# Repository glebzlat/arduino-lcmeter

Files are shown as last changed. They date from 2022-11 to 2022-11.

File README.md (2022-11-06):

## Arduino LC-meter

Простой измеритель емкости/индуктивности на Arduinо. Диапазон измерений: от ~90 пФ/мкГн до ~6 мкФ/Гн.

### Функционал

Кнопка J2 Calibration служит для программной коррекции нуля, что компенсирует начальное смещение нуля ОУ, а также емкость и индуктивность клемм и переключателя SW1. Нужный диапазон выбирается автоматически, причем после включения питания измерение начинается с 9 диапазона.

В процессе переключения диапазонов частота возбуждающего напряжения и результат преобразования АЦП отображаются в нижней строке индикатора. Это справочная информация, которая может помочь оценить корректность измерения параметров. Через несколько секунд после стабилизации показаний эта строка индикатора очищается, чтобы не отвлекать внимание пользователя.

Результат измерения отображается в верхней строке. Измеренное значение напряжения с выхода ОУ интерпретируется как емкость или индуктивность в зависимости от положения переключателя J3 MODE.

### Настройка

Прибор имеет два подстроечных резистора, предназначенных для настройки правильности показаний значения емкости и индуктивности. Их надо настроить после сборки и в дальнейшем трогать их не нужно. Для этой процедуры требуется парочка конденсаторов и индуктивностей с точностью хотя бы 5%.

### Как это работает

Принцип измерения заключается в подаче меандра на измеряемый конденсатор или индуктивность и преобразовании тока разряда конденсатора (или тока индуктивности) в напряжение, которое сглаживается и подается на АЦП Arduino. При измерении емкости конденсатор во время положительного полупериода заряжается через резистор R6 и диод D5, во время отрицательного разряжается через резистор R6 и диод D1, и его разрядный ток поступает на вход 2 U1. При измерении индуктивности во время положительного полупериода ток в катушке нарастает до значения, определяемого номиналом резистора R7, а во время отрицательной - ток, создаваемый ЭДС самоиндукции через D2 и R2, RV2 также поступает на вход U1. Ток разряда конденсатора (а, значит, и напряжение на выходе измерителя) прямо пропорционален его емкости, если конденсатор успевает полностью зарядиться за положительный полупериод и полностью разрядиться за отрицательный. Также и ток самоиндукции катушки прямо пропорционален ее индуктивности, если ток в ней успевает нарастать до максимального значения и спадать до нуля.

Для этого частота автоматически изменяется от 1 мегагерца до 15 герц в зависимости от значения напряжения на выходе измерителя. Прибор имеет 9 диапазонов измерения, и на каждом последующем диапазоне частота снижается, а предел измерения увеличивается в 4 раза. На первом диапазоне частота равна 1 МГц, и максимальное измеряемое значение ~90 пФ/мкГн.

| Диапазон | Частота (МГц) | Макс. емкость (Ф) | Макс. индуктивность (Гн) |
|---|---|---|---|
| 1 | 1.000.000 | 8,92e-11 | 8,92e-5 |
| 2 | 250.000 | 3,56e-10 | 3,56e-4 |
| 3 | 62.500 | 1,42e-9 | 1,42e-3 |
| 4 | 15.625 | 5,70e-9 | 5,70e-3 |
| 5 | 3.906 | 2,28e-8 | 2,28e-2 |
| 6 | 976 | 9,13e-8 | 9,13e-2 |
| 7 | 244 | 3,65e-7 | 3,65e-1 |
| 8 | 61 | 1,46e-6 | 1,46 |
| 9 | 15 | 5,84e-6 | 5,84 |

### Источники

https://ra4nal.ontvtime.ru/lc_arduino.shtml

Журнал Радио №3 1982

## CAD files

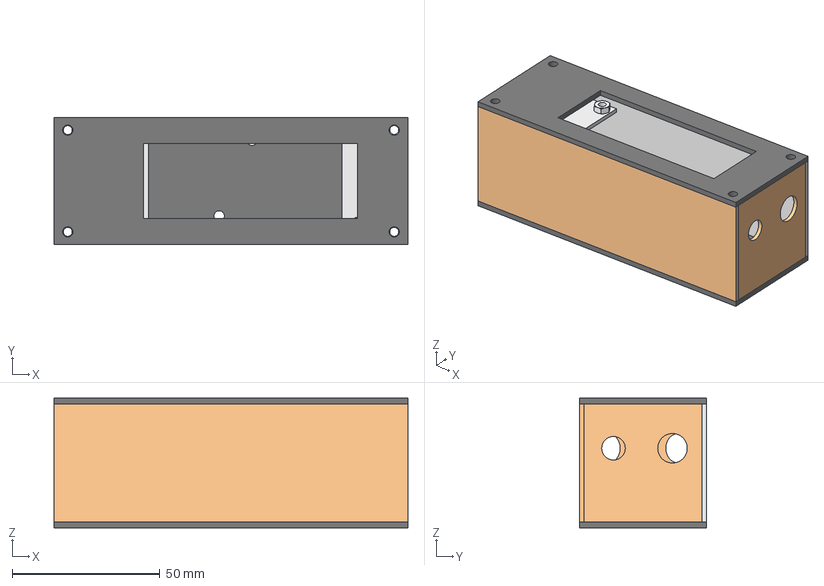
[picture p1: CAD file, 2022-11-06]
lc_meter_frame.FCStd
120.0 x 43.0 x 44.0 mm
Screw M3 001
Screw M3 001 (Mirror #2)
Screw M3 001 (Mirror #3)
Screw M3 001 (Mirror #1)
Screw M3 001 (Mirror #5)
Screw M3 001 (Mirror #6)
Screw M3 001 (Mirror #7)
Screw M3 001 (Mirror #4)
Screw M3 002
Screw M3 003
Screw M3 004
Screw M3 005
Side Panel 2
Side Panel 4
Side Panel 3
Side Panel 1
Bottom Panel
Top Panel

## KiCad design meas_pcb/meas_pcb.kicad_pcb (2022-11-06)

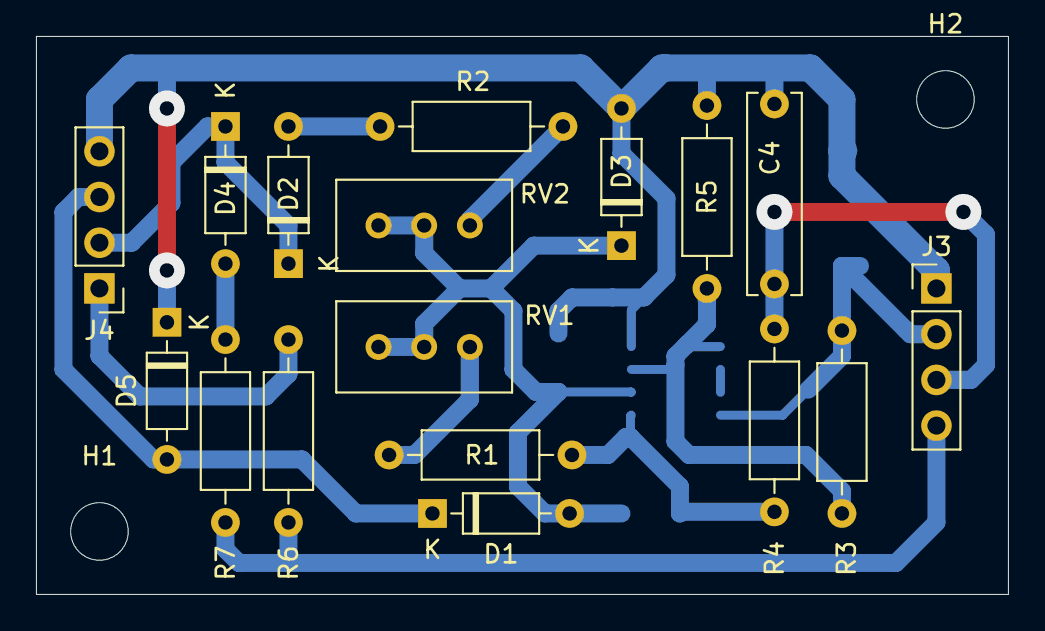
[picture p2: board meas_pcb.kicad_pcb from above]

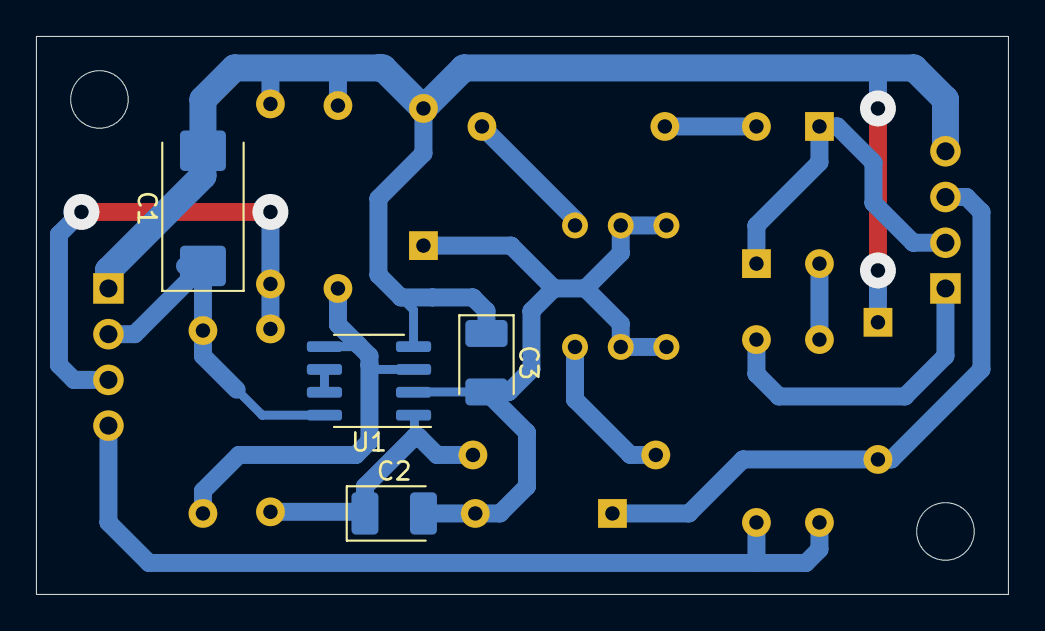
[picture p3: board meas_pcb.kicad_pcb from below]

Board: 2 copper layers, 54.0 x 31.0 mm, 23 parts (4 on the bottom side), 15 nets.

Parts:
C1: 22u; CP_EIA-7343-31_Kemet-D_Pad2.25x2.55mm_HandSolder
C2, C3: 47u; CP_EIA-3528-21_Kemet-B_Pad1.50x2.35mm_HandSolder
C4: 1000p; C_Rect_L11.0mm_W2.8mm_P10.00mm_MKT
D1, D2, D4, D5: BAT41; D_DO-35_SOD27_P7.62mm_Horizontal
D3: 1N4148; D_DO-35_SOD27_P7.62mm_Horizontal
H1, H2: MountingHole; MountingHole_3.2mm_M3
J3, J4: Conn_01x04; PinHeader_1x04_P2.54mm_Vertical
R1: 4.7k; R_Axial_DIN0207_L6.3mm_D2.5mm_P10.16mm_Horizontal
R2: 560; R_Axial_DIN0207_L6.3mm_D2.5mm_P10.16mm_Horizontal
R3: 47k; R_Axial_DIN0207_L6.3mm_D2.5mm_P10.16mm_Horizontal
R4: 3.3k; R_Axial_DIN0207_L6.3mm_D2.5mm_P10.16mm_Horizontal
R5, R7: 1k; R_Axial_DIN0207_L6.3mm_D2.5mm_P10.16mm_Horizontal
R6: 300; R_Axial_DIN0207_L6.3mm_D2.5mm_P10.16mm_Horizontal
RV1: 10k; Potentiometer_Bourns_3296W_Vertical
RV2: 1k; Potentiometer_Bourns_3296W_Vertical
U1: MCP6002-xMS; SOIC-8_3.9x4.9mm_P1.27mm

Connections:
/Vcc: C1.1, J3.2, R3.1, U1.8
GND: C1.2, C3.1, C4.2, D3.2, D5.1, J3.1, J4.4, R5.2, U1.4
unnamed: C2.1, R1.1, R4.2, U1.1
unnamed: C2.2, C3.2, D1.2, D3.1, RV1.1, RV1.2, RV2.1, RV2.2, U1.2
unnamed: C4.1, J3.3, R4.1
unnamed: D1.1, D5.2, J4.3
unnamed: D2.1, D4.1, J4.2
unnamed: D2.2, R2.2
unnamed: D4.2, R7.1
unnamed: J3.4, R6.2, R7.2
unnamed: J4.1, R6.1
unnamed: R1.2, RV1.3
unnamed: R2.1, RV2.3
unnamed: R3.2, R5.1, U1.3, U1.5
unnamed: U1.6, U1.7

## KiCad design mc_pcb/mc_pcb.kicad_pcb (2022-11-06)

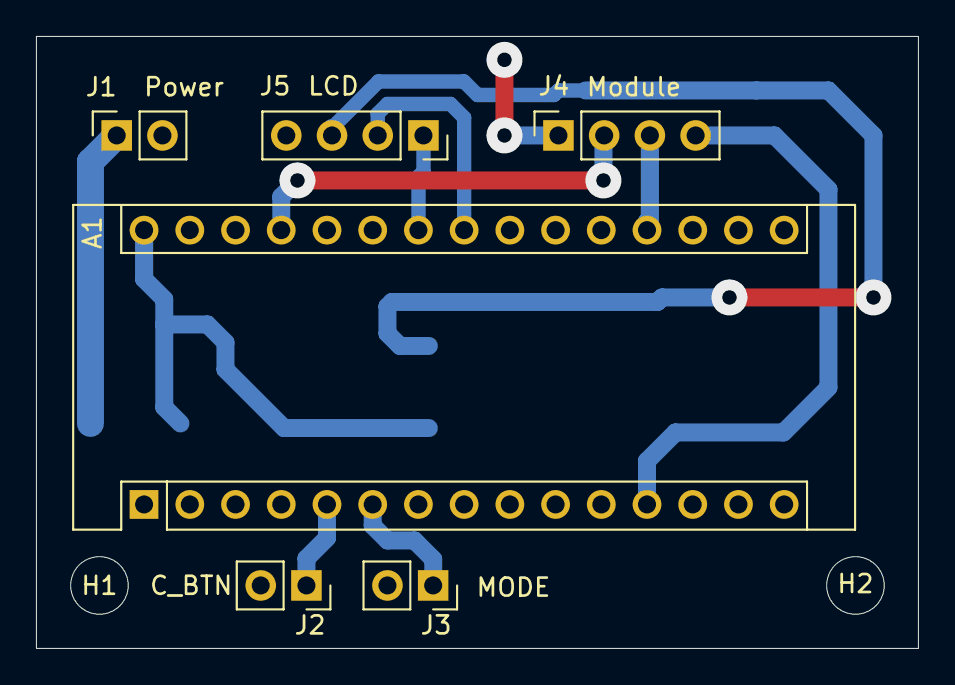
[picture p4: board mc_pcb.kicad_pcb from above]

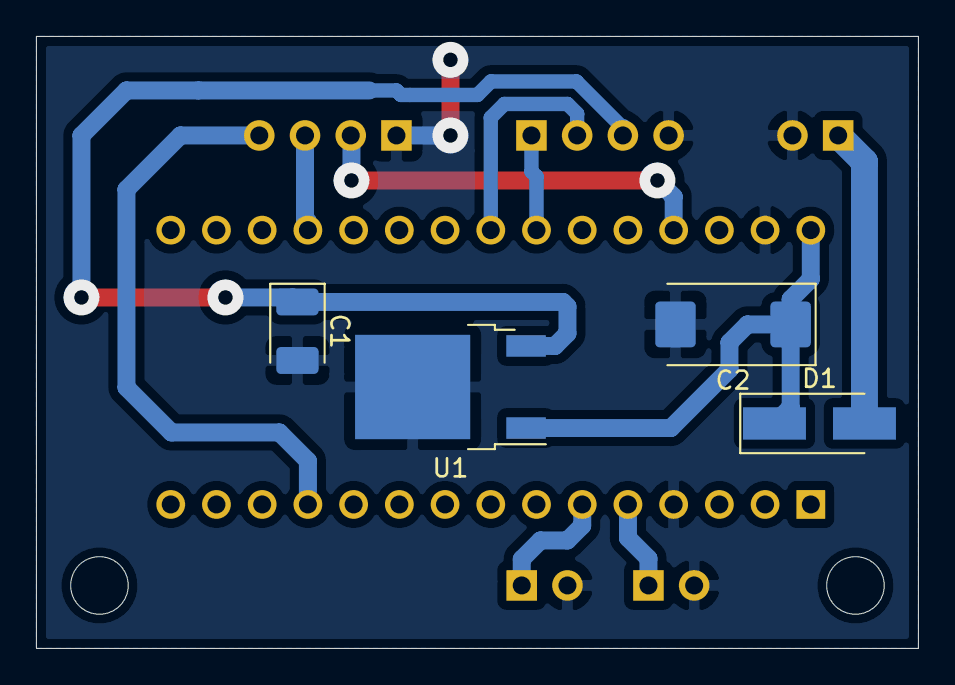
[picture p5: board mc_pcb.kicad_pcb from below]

Board: 2 copper layers, 49.0 x 34.0 mm, 12 parts (4 on the bottom side), 11 nets.

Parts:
A1: Arduino_Nano_v3.x; Arduino_Nano
C1: 47u; CP_EIA-3528-21_Kemet-B_Pad1.50x2.35mm_HandSolder
C2: 22u; CP_EIA-7343-31_Kemet-D_Pad2.25x2.55mm_HandSolder
D1: 1N4004; D_SMA_Handsoldering
H1, H2: MountingHole; MountingHole_3.2mm_M3
J1: Power; PinSocket_1x02_P2.54mm_Vertical
J2: C_BTN; PinSocket_1x02_P2.54mm_Vertical
J3: MODE; PinSocket_1x02_P2.54mm_Vertical
J4: Module; PinSocket_1x04_P2.54mm_Vertical
J5: LCD; PinSocket_1x04_P2.54mm_Vertical
U1: LM78M05_TO252; TO-252-2

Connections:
/FRQ: A1.12, J4.4
/VCC: A1.27, J4.2
/VDD: C1.1, J5.3, U1.3
GND: A1.4, A1.29, C1.2, C2.2, J1.2, J2.2, J3.2, J4.1, J5.4, U1.2
unnamed: A1.5, J2.1
unnamed: A1.6, J3.1
unnamed: A1.19, J4.3
unnamed: A1.23, J5.2
unnamed: A1.24, J5.1
unnamed: A1.30, C2.1, D1.1, U1.1
unnamed: D1.2, J1.1

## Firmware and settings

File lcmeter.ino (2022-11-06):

//LC-метр v 071 rev B
//original           https://ra4nal.ontvtime.ru/lc_arduino.shtml
//LiquidCrystal_I2C  https://github.com/johnrickman/LiquidCrystal_I2C
//fastRead function  https://alexgyver.ru/arduino-algorithms/
//_edKotinsky        https://vk.com/dudewhodied

//  |   Range  | frequency | max value
//  |   1(0)   | 1,000,000 |  892       
//  |   2(1)   | 250,000   |  3,568
//  |   3(2)   | 62,500    |  14,272 
//  |   4(3)   | 15,625    |  57,088
//  |   5(4)   | 3,906     |  228,352
//  |   6(5)   | 976       |  913,408
//  |   7(6)   | 244       |  3,653,632
//  |   8(7)   | 61        |  14,614,528
//  |   9(8)   | 15        |  58,458,112

//  диапазоны считаются от нуля до 8 [0; 8]
//  на каждом диапазоне частота уменьшается в 4 раза  freq = 1,000,000 / 4^diap
//  диапазон измерения увеличивается соответственно в 4 раза
//  истинное измеряемое значение value = resultADC * 4^diap
//  последний разряд результата - 0.1, т.е 892 = 89.2 пФ

#include <Wire.h>
#include <LiquidCrystal_I2C.h>
#include <EEPROM.h>

//  выбрать дефайн, соответствующий частоте ядра
//#define CPU_FREQ_8MHZ
#define CPU_FREQ_16MHZ

#define C_BTN       2       //  вывод для кнопки калибровки
#define M_SW        3       //  вывод для переключателя режимов

#define NDIAP       8       //  количество диапазонов
#define STAB_TIME   500     //  время между заданием частоты таймеру и чтением АЦП
#define DMIN        192     //  минимальное значение для переключения диапазона
#define DMAX        892     //  максимальное значение для переключения диапазона
#define MAX_CALIB   192     //  максимальное значение при калибровке

#define MODE_C      0x0
#define MODE_L      0x1

LiquidCrystal_I2C lcd(0x27, 16, 2);

void lcdcl (uint8_t row = 0) {
  lcd.clear();
  lcd.setCursor(0, row);
}

void lcdline (uint8_t row = 0) {
  lcd.setCursor(0, row);
  lcd.print(F("                "));
}

bool fastRead(const uint8_t pin) {
  if (pin < 8) {
    return bitRead(PIND, pin);
  } else if (pin < 14) {
    return bitRead(PINB, pin - 8);
  } else if (pin < 20) {
    return bitRead(PINC, pin - 14);
  } else {
    return 0;
  }
}

  //mode switch condition
bool modeSwitch (uint8_t pin) {
  return fastRead(pin);     //0 - C mode, 1 - L mode
}

  //calibration button handler
bool button (const uint8_t pin, uint32_t debounce) {
  static uint32_t prevMillis = 0;
  static bool flag = 0;

  bool btnState = !fastRead(pin);
  
  if (btnState && !flag && millis() - prevMillis > debounce) {
    flag = 1;
    prevMillis = millis();
  }
  if (!btnState && flag &&millis() - prevMillis > debounce) {
    flag = 0;
    prevMillis = millis();
  }

  return flag;
}

  //configure timer1, wait for stabilization time, start ADC convertion and return result
int16_t freqAndRead (uint8_t diap, bool& flag) {
  //                    fclk_I/O
  //    fOC1A = -----------------------
  //            2 · presc · (1 + OCR1A)

  static uint32_t  prevMillis = 0;
  int16_t result  = 0;
  uint16_t top    = 2;

  #if defined CPU_FREQ_8MHZ 
    uint8_t pwr = 2 * diap + 2;
  #elif defined CPU_FREQ_16MHZ
    uint8_t pwr = 2 * diap + 3;
  #endif
  
  ADCL = 0x0;
  ADCH = 0x0;

  //configure timer1
  TCCR1A =   0b01000000;            //COM1A0  CTC mode with top on OCR1A
  if (diap < 3) {
    TCCR1B = 0b00001001;            //WGM12 | CS10  presc = 1
  } else {
    TCCR1B = 0b00001100;            //WGM12 | CS12  presc = 256
    
    #if defined CPU_FREQ_8MHZ 
      pwr = pwr - 7;
    #elif defined CPU_FREQ_16MHZ
      pwr = pwr - 8;
    #endif
  }

  if (pwr != 0) {
    for (uint8_t i = 1; i < pwr; ++i) {
      top = top << 1;               //top^pwr
    }
  } else {
    top = 1;
  }
  
  if (--top != OCR1A) {             //if top != previous top, range changed 
    TCNT1H = 0x0;                   //so reset timer counter
    TCNT1L = 0x0;   
    OCR1A = top;                    //write new top value to OCR
    prevMillis = millis();          //and reload delay
  }

  //wait 0.5 second to stabilize voltage on the module output
  if (millis() -  prevMillis > STAB_TIME) {              
    while (!(PINB & 0b00000010));   //wait two signal changes
    while (PINB & 0b00000010);      //and 6 mS to get value at the 
    delay(6);                       //particular moment
    ADCSRA |= (1 << ADSC);          //start adc convertion
    do {                            //while convertion is in process  
      SMCR = 0b00000011;            //SM0 | SE  enable ADC noise reduction sleep mode
    } while (ADCSRA & (1 << ADSC)); //wait until convertion complete
    flag = 1;                       //then set the result ready flag
    result = ADC;                   //read adc result register
    prevMillis = millis();          //and set current millis value to prevTime
  }

  return result;
}

  //print the calibration state
void calibrationMsg (bool error) {
  lcd.print(F("Calibration "));
  if (error) {
    lcd.print(F("err"));
  }
}

  //print range and ADC value to display
void printRL (uint8_t diap, int16_t value) {
  lcd.setCursor(0, 1);
  lcd.print(F("range "));
  lcd.print(diap);
  lcd.print(F(" ADC "));
  lcd.print(value);
}

uint8_t getCountOfDigits (int32_t number) {
  int count = (number == 0) ? 1 : 0;
  while (number) {
    ++count;
    number /= 10;
  }

  return count;
}

  //interpretate and print result
uint8_t convertAndPrint (int32_t result, uint8_t diap, uint8_t startPos) {
  uint8_t commaNum    = 1;
  uint8_t totalLength = 0;
  uint8_t numCounter  = 0;
  uint8_t num         = 0;
  bool roundCont      = 0;
  uint8_t resLen      = 0;
  
  while (diap) {
    --diap;                               //result = resultADC * 4^diap
    result = result << 2;                 //result * 4 while diap != 0
  }

  resLen = getCountOfDigits(result);
  if (resLen < 2) ++resLen;
  
  if (resLen >= 5) {                      //number of the decimal separators
    commaNum = 2;                         //depends of number of result symbols
    if (resLen > 7) {                     //1,000.0   - 5 digit, 2 decimal separators
      commaNum = 3;                       //100,000.0 - 7 digit, 3 decimal separators
    }                                     //100.0     - 4 digit, 1 decimal separators
  }

                                          //totalLength is a column, on which result printing ends
  totalLength = resLen + startPos + commaNum - 1;
                                          //loop recursively goes by number from the least significant digits and prints result from end 
  for (uint8_t i = totalLength; i >= startPos; --i) {
    lcd.setCursor(i, 0);
    if (i == totalLength - 1) {           //legth - 1 - is a decimal
      lcd.print('.');                     //they are separated by the dot
      numCounter = 0;                     //when it happens, digit counter is reset
    } else if (numCounter == 3) {         //every three digits
      lcd.print(',');                     //print the comma
      numCounter = 0;                     //and reset digit counter to zero
    } else {                              //if not a decimal separator, then print the digit
      num = result % 10;                  //get the number from current digit
      if (i > startPos + 3) {             //if loop do not goes the three high significant digits
        if (num > 5) {                    //if the number of current digit is > 5
          roundCont = 1;                  //set the rounding flag
        }                                 //and reset number of current digit to zero
        num = 0;
      }
      lcd.print(num);
      result /= 10;                       //discard the current digit
      if (roundCont) {                    //if in the discarded digit was a rounding to high 
        result += 1;                      //add 1 to the current digit number
        roundCont = 0;                    //and reset rounding flag
      }
      if (result) ++numCounter;           //count printing digits
    }
  }

  return totalLength;    //totalLength is a column, on which result printing ends
}

void printResult (uint8_t diap, int16_t value, bool mode) {
  uint8_t printCol = 2;
  lcd.setCursor(0, 0);
  if (mode == MODE_C) lcd.print(F("C"));
  else                lcd.print(F("L"));
  printCol += convertAndPrint(value, diap, printCol);
  lcd.setCursor(printCol, 0);
  if (mode == MODE_C) lcd.print(F("pF"));
  else                lcd.print(F("uH"));
}

void setup() {
  //ADC setup
  ADMUX  = 0b01000000;      //REFS0 | MUX3:0 = 0, input ADC0
  
  #if defined CPU_FREQ_16MHZ
    ADCSRA = 0b10000111;    //ADEN | ADPS2:0 prescaler = 128
  #elif defined CPU_FREQ_8MHZ
    ADCSRA = 0b10000110;    //ADEN | ADPS2:1 prescaler = 64
  #endif
  
  //first ADC convertion to initialize ADC
  ADCSRA |= (1 << ADSC);

  //pin modes
  pinMode(9, OUTPUT);           //FRQ output
  pinMode(C_BTN, INPUT_PULLUP); //calibration button
  pinMode(M_SW, INPUT_PULLUP);  //mode switch

  //lc display
  lcd.begin(16, 2);
  lcd.backlight();
}

void loop() {
  static uint8_t diap = NDIAP;
  static bool flag        = 0;
  static bool calibration = 0;
  static bool mode        = 0;

  int16_t result    = 0;
  uint16_t eeAddr   = 0;
  bool resultReady  = 0;
  bool error        = 0;
  
  if (mode != modeSwitch(M_SW)) {         //mode switch state
    if (calibration) {          
      calibration = 0;
      diap = NDIAP;
    }
    mode = !mode;
  }
  if (!calibration && button(C_BTN, 100)) { //if calibration
    diap = NDIAP;                         //reset range
    calibration = 1;
  }
  
  result = freqAndRead(diap, resultReady);
  
  if (resultReady) {                      //once a 0.5 second
    lcdcl();

    if (mode == MODE_C) eeAddr = diap;    //calibration values: c measurement mode EEPROM [0; 8]
    else  eeAddr = eeAddr + NDIAP + 1;    //                    l measurement mode EEPROM [9; 17]

    if (calibration) {                    //  CALIBRATION
      if (result < MAX_CALIB) {
        EEPROM.update(eeAddr, lowByte(result));
      } else {
        error = 1;
      }

      calibrationMsg(error);
      printRL(diap, result);      

      if (diap) {                         //calibration lasts up to range == 0
        --diap;                           //diap e [0; 8]
      } else {
        calibration = 0;      
      }
    } else {                              //  MEASURIMENT
      bool diapChanged = 0;
      
      if (result > DMAX && diap < NDIAP) {
        printRL(diap, result);
        ++diap;
        flag = 1;
        diapChanged = 1;
      }
      if (result < DMIN && diap) {
        printRL(diap, result);
        --diap;
        flag = 1;
        diapChanged = 1;
      }

      if (flag) {                         //if the range has been changed
        if (!diapChanged){                //and now range is not changed
          printRL(diap, result);          //print current range
          flag = 0;                       //and clear change flag
        } else 
          lcdline();                      //clear the first line
      } 
      
      if (!flag ){                        //if the range hasnt been changed
        result = result - EEPROM.read(eeAddr);  //calculate and print result value
        result = constrain(result, 0, 1023);
        printResult(diap, result, mode);
      }
    }
  }
}
